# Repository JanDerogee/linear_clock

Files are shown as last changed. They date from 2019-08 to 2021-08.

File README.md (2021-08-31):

# linear_clock
A clock that shows time on a line instead of a circle.

Because sometimes, showing time in a different way can be easier.
Some people, mostly children have problems of reading time froma regular clock.
Times goes around in circles, but sometimes you just want to know where you are in a day.
This linear clock has one unique position for each moment of the day.
It is a true 24 hour clock. The night and morning are on the left of the scale, the afternoon and evening are on the right.
The clock reaches it highest point at the same time the sun does (well... theoretically, as this depends on your timezone).

The clock is simple in construction, requires just one single stepper motor and is based on an ESP8266 and a threaded rod.

For more information:
https://janderogee.com/projects/linear_clock/linear_clock.html

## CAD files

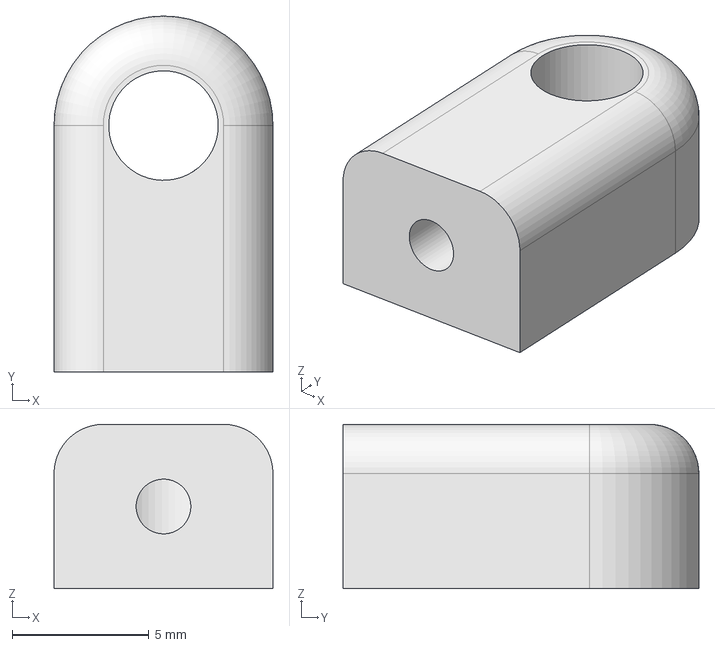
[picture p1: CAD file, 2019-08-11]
3d_printed_parts/lc_alarm_endcap.FCStd
8.00 x 13.0 x 6.00 mm

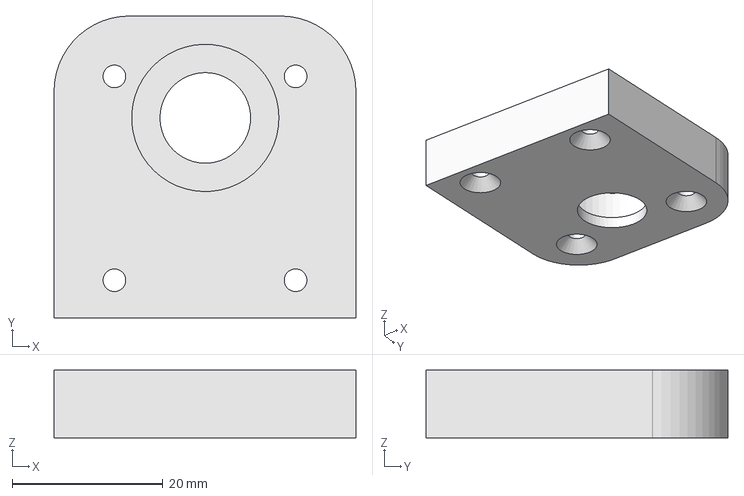
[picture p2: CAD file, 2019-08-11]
3d_printed_parts/lc_bearing_mount.FCStd
40.0 x 40.0 x 9.00 mm

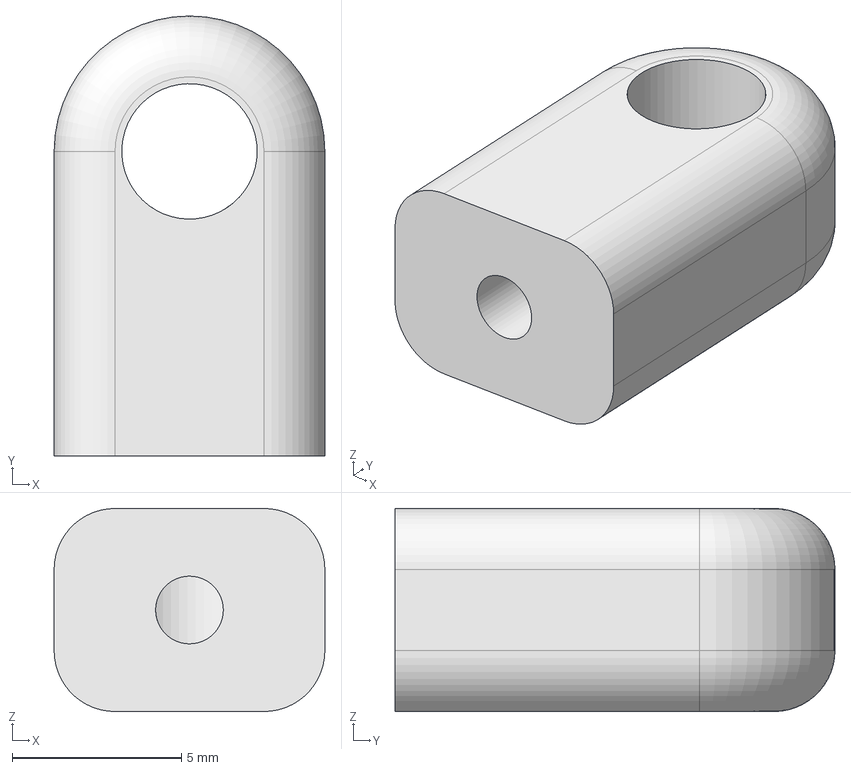
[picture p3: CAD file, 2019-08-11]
3d_printed_parts/lc_alarm_support.FCStd
8.00 x 13.0 x 6.00 mm

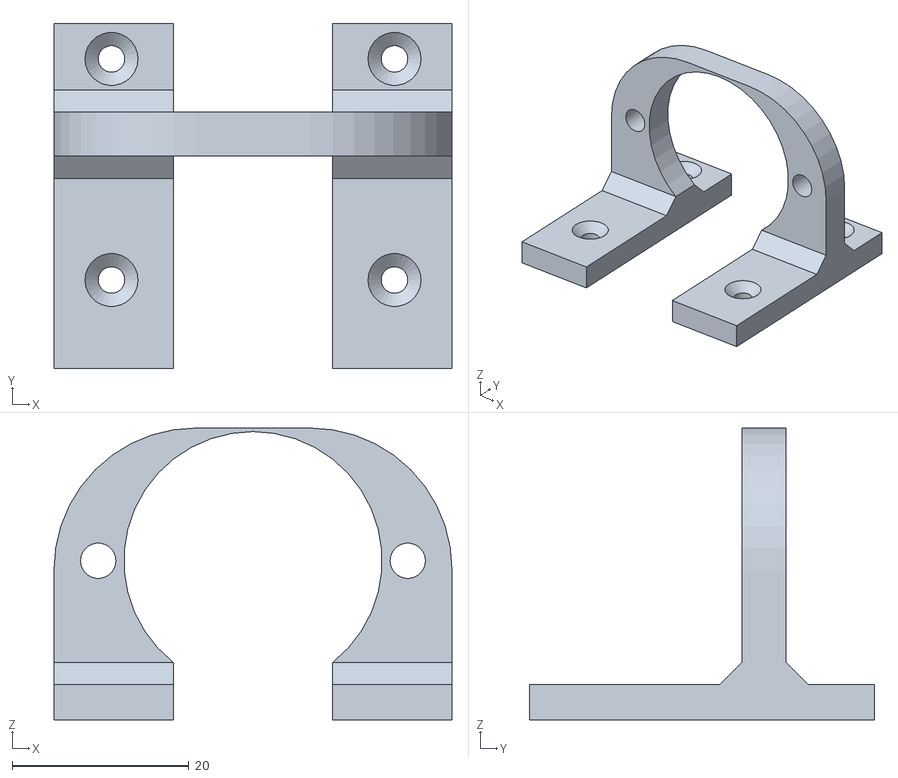
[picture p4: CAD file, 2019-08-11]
3d_printed_parts/lc_motor_mount.stl
45.0 x 39.0 x 33.0

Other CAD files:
3d_printed_parts/lc_moter_mount.FCStd
3d_printed_parts/lc_alarm_endcap.stl
3d_printed_parts/lc_alarm_support.stl
3d_printed_parts/lc_bearing_mount.stl

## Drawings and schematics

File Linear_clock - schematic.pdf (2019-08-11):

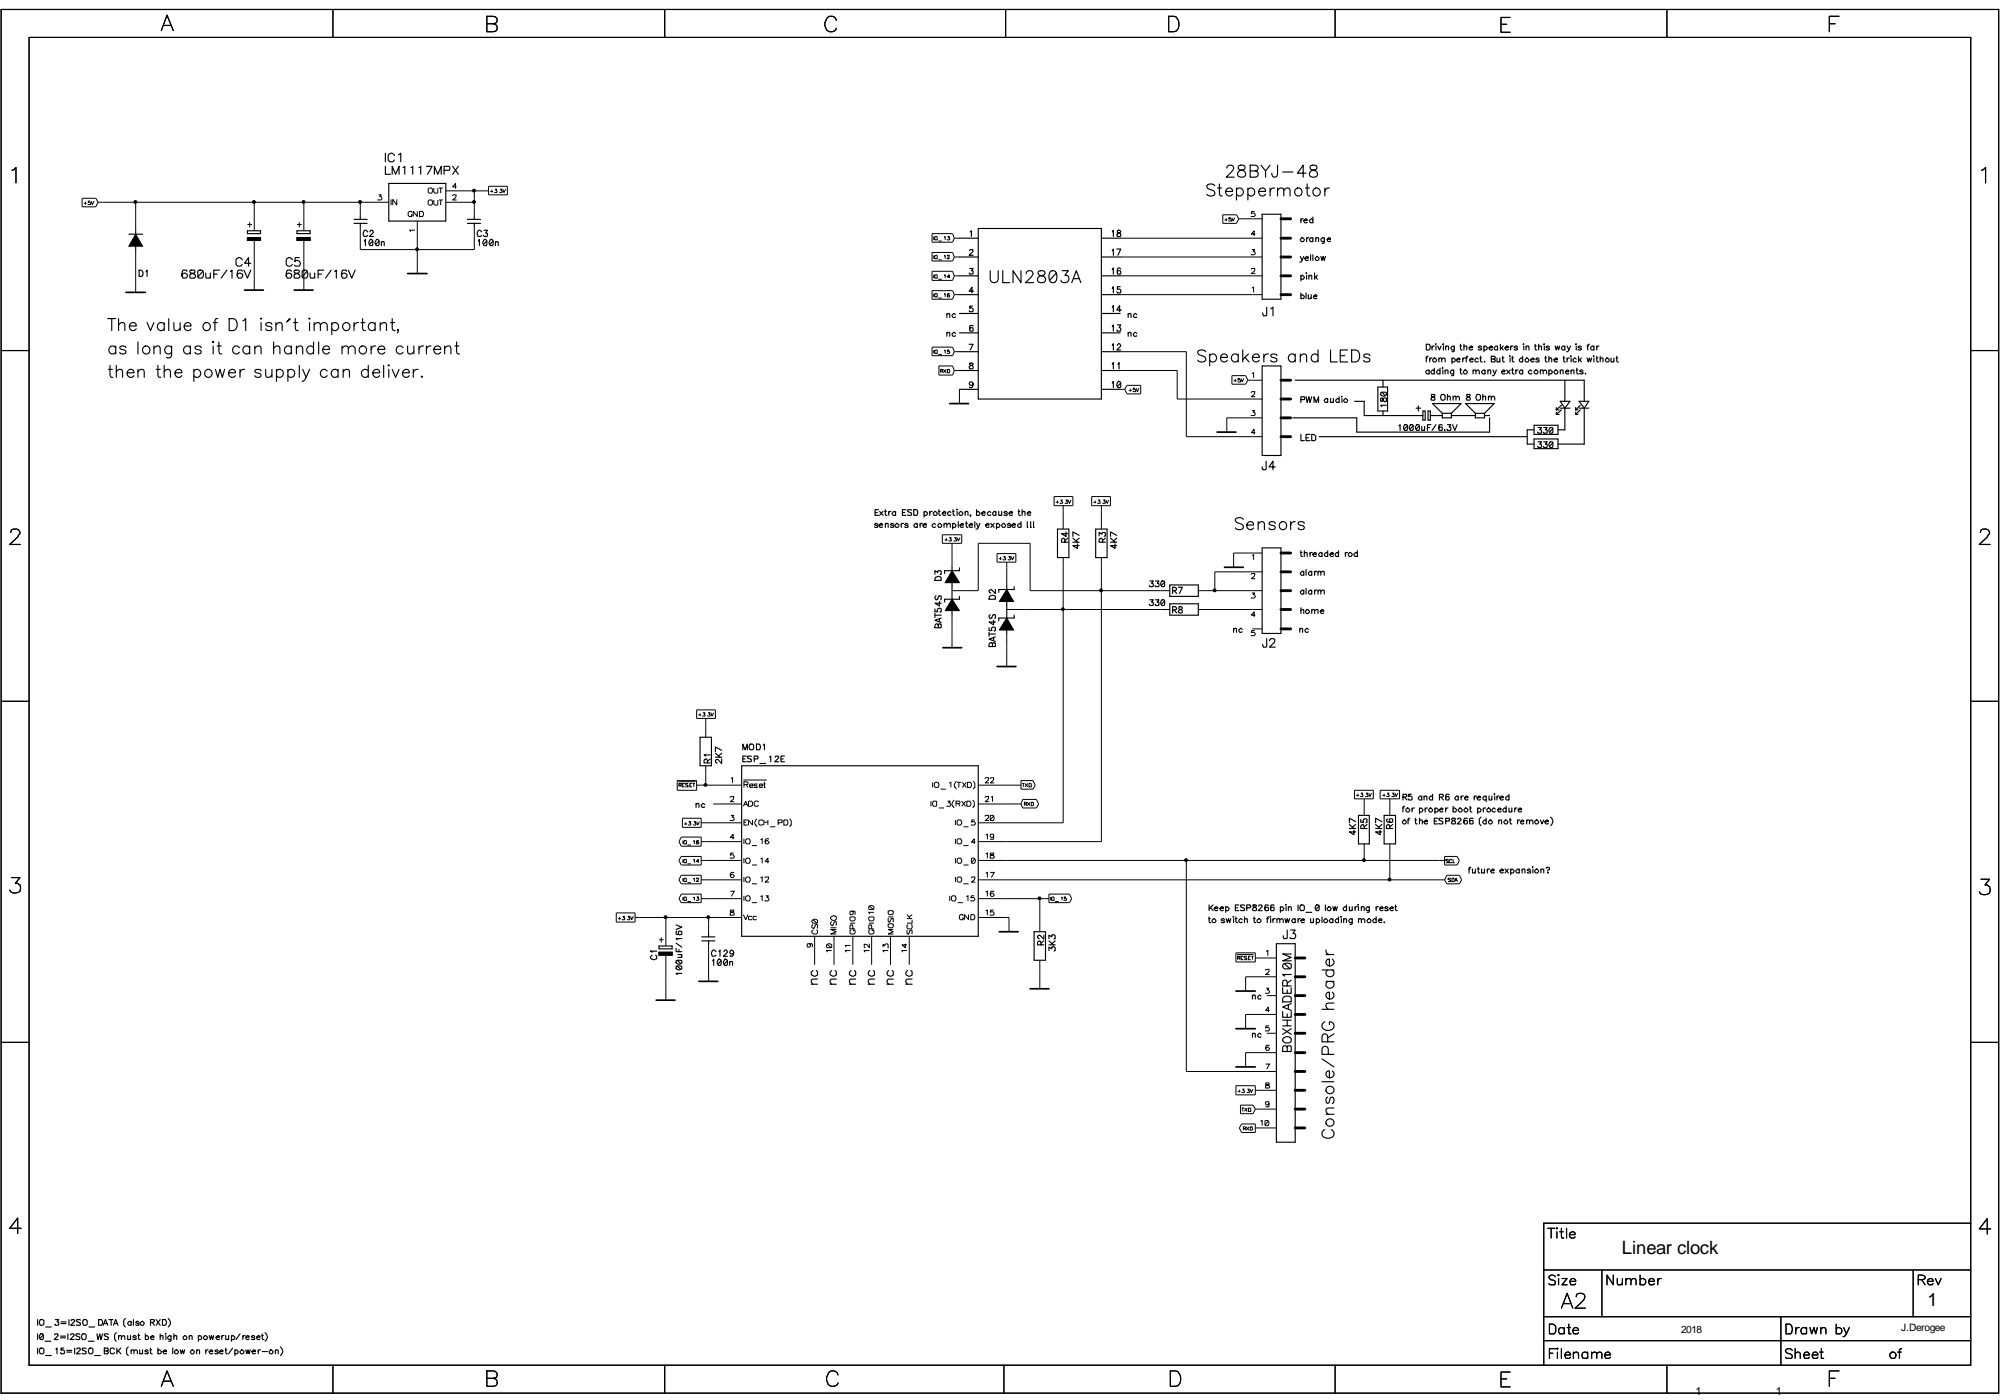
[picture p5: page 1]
Linear clock; J.Derogee

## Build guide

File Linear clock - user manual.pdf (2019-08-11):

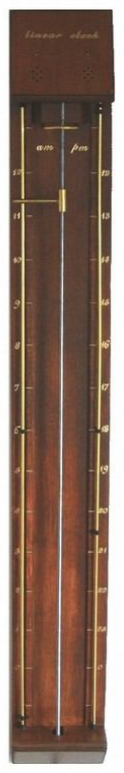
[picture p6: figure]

# Linear clock

## user manual

## Introduction

This manual describes the functionality and configuration of the linear clock. The linear clock is a project made by Jan Derogee. The entire project was created with the idea to make the mechanical part a simple as possible. This mainly with the intention that it could be easily reproduced by anyone. No special hardware or expensive parts required, only cheap and “off the shelf” parts that can be found in most hardware stores. This project also does not require the use of special limit switches, brushed contacts or an expensive spindle or nut.

I wanted to make this clock for many years but never took the time because I felt that it should be as easy to use as possible with the minimum of components, no display no buttons. It was mostly the revolution of the ESP8266 wifi module that made this project possible in an affordable (extremely cheap) and practical manor.

2018-05-07 | Page 2 of 13 | Linear clock – user manual

## Table of Contents

2018-05-07 | Page 3 of 13 | Linear clock – user manual

## 1 The linear clock

### 1.1 Concept

The idea behind the linear clock is mainly to be a different kind of time indicator. This because for some kind of people, indicating time by two rotating indicators isn't as easy as for others. For some it is far from convenient for others it is plainly confusing. In those cases a linear clock could be of use to small children who are not familiar with the concept of or capable of telling time using conventional clock. But for those who don't have trouble reading regular clocks, a linear clock can still be pretty to look at, decorating your wall and be a nice conversation starter when you have a visitor.

By representing time on a line (where the left side of the line represent night and morning and the right side represents afternoon and evening the complete overview of the current time/position of the day is indicated.

Indicating constantly repeating events at specific times along the day (think of breakfast, lunch, diner) is much easier when the whole day is represented. This could be of great use for learning rhythm and the concept of time to small children but could certainly be helpful in creating order and structure for autistic people who lack the skill of the concept of time and therefore cannot handle the method of representing the conventional way of displaying time.

### 1.2 Definition of the time scale

As can be seen on the photo on the next page, the timescale is defined in 2 sides. The left side (where the pointer moves upwards) indicates the time 00:00 – 11:59 and represents night and morning also known as AM. The right side of the clock indicates the time 12:00 – 23:59 and therefore represents afternoon and evening also known as PM.

Looking at the scale it becomes clear that the pointer moves in a similar way like the sun in our sky, it rises in the morning and sets in the afternoon.

2018-05-07 | Page 4 of 13 | Linear clock – user manual

## 2 The clock's parts

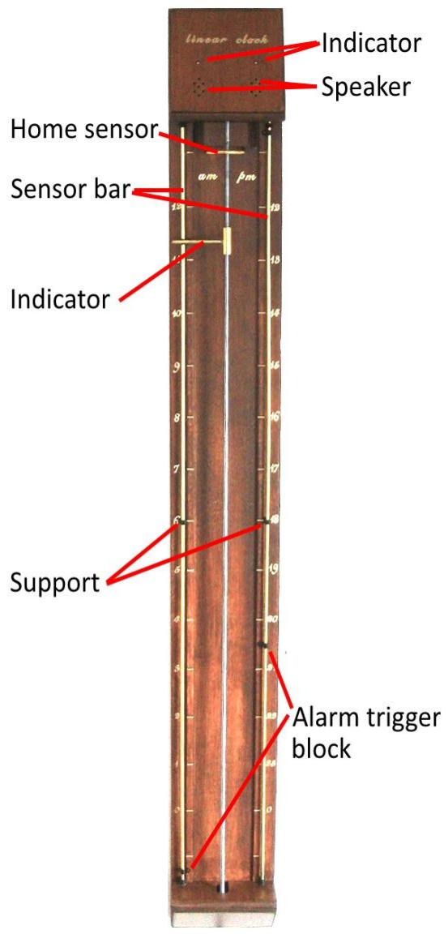
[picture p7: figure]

2018-05-07 | Page 5 of 13 | Linear clock – user manual

## 3 Configuration

This chapter will describe how to connect to the configuration page of the linear clock with an ordinary web browser and phone/tablet.

### 3.1 Connecting to your home network

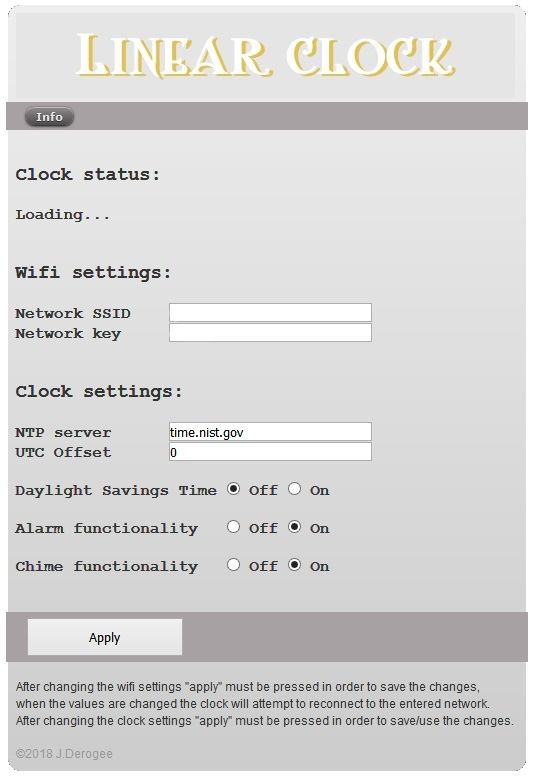
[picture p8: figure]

The linear clock has several settings that are required for correct operation. And although the clock has no display or button, it does feature a convenient web-interface through which these values can be altered.

However… when you first use the linear clock, it has no configuration for connecting to your home network and therefore it cannot connect to it. In order to allow you to access this configuration web-interface, the clock must create it's own network. Therefore allowing you to connect to it using your mobile phone or tablet.

This is what you need to do on your phone/tablet:

Step 1: go to the wifi configuration page of your phone/tablet
Step 2: scan through the list of available networks
Step 3: connect to the network Linear clock
Step 4: open a web browser on your phone/tablet
Step 5: enter the IP address 192.168.1.1 as an URL in your browser
Step 6: after a few seconds the configuration page will appear in your browser
Step 7: make sure you have the correct SSID and KEY values of your home network at hand
Step 8: change the settings of the SSID and KEY to the values of your home network
Step 9: when you've changed the values and pressed the apply button the created network Linear clock, will close and the clock will attempt to connect to your home network
Step 10: when SSID and KEY are correct, a cheerful sound will be heard and the LED will turn off. The clock will also be accessible through a browser on any computer/phone/tablet connected to your home network.

But when the settings are not correct, it will fail and you must return to step 3:

2018-05-07 | Page 6 of 13 | Linear clock – user manual

### 3.2 Settings

Below a screenshot of the configuration page of the linear clock. Although some settings are self explanatory, the next few chapters will describe each function in detail.

2018-05-07 | Page 7 of 13 | Linear clock – user manual

### 3.2.1 SSID

The SSID field should hold the name of your home network.

### 3.2.2 Key

The Key field should hold the network key (or password) of your home network.

### 3.2.3 NTP server

The linear clock requires an NTP server in order to function. Because this is where the clock get's the time from. The clock set's it's own internal clock to the NTP server time reference and is therefore very accurate. The NTP server is contacted every hour to keep the linear clock counter as accurate to the real time as possible.

A very good time server (and therefor set as the default value) is: time.nist.gov But if for some reason this fails to function there are many others and the clock allows you to change that setting.

### 3.2.4 UTC offset

The time that is received from the NTP server is according to the “coordinated universal time” or UTC for short. UTC is not affected in any way, so local jurisdictions regarding time zones or daylight saving time situations have no effect on the UTC value. This means that it is a world wide accepted universal time value that always requires an offset to be added in order to get the local time. For instance

Greenwich = UTC+0 | therefore fill in 0 in the UTC offset field if you use the clock there
Amsterdam = UTC+1 | therefore fill in 1 in the UTC offset field if you use the clock there
Chicago = UTC-6 | therefore fill in -6 in the UTC offset field if you use the clock there

For places that have timezones that are not a multiple of an whole hour an extra value can be added after the hour. But this fraction isn't in minutes but in parts of an hour. Therefore 15 minutes is 0.25 (because 15 minutes is 0.25 * 60). 30minutes is 0.5, 45 minutes is 0.75, etc.

Venezuela = UTC−4:30 | therefore fill in -4.5 in the UTC offset field if you use the clock there
Nepal = UTC+5:45 | therefore fill in 5.75 in the UTC offset field if you use the clock there

For more information about timezones you can visit https://en.wikipedia.org/wiki/Time_zone

Keep in mind that the offset from UTC is always without DST, in other words the offset is always related to wintertime. In order to add an extra hour because of summertime you should turn the DST setting to ON. Do not add the extra DST hour to your UTC offset setting but use the DST ON/OFF twice a year to switch between winter- (off) or summer-time (on).

Note:

If your life in an area that uses daylight savings time and it is summer time then if you life for example in a timezone that has an offset of +1 related to UTC, then do not fill in +2 to make the displayed time on the clock be correct. Just use offset +1 and set DST to ON. That would be the only correct way to configure your clock.

2018-05-07 | Page 8 of 13 | Linear clock – user manual

### 3.2.5 Daylight savings time

Daylight savings time or DST for short is a method of saving energy by messing with the clock. Therefore using the daylight more efficiently energy resources are less needed. Now this sounds nice in theory but in practice it is all very confusing because there are different DST changeover moments through the world, twice a year. Therefore in order to keep the design of the clock as easy as possible, DST is not automatic. Therefore the user must change the setting from OFF to ON and vice versa twice a year. When the summer begins DST should be set to ON and during winter DST should be set to OFF. The only thing that happens when DST is ON is that an extra hour is added to the local time.

### 3.2.6 Alarm

The clock features an alarm function, by placing alarm blocks along the brass sliders alarm event can be generated when the indicator passes over them. This functionality can be completely disabled, meaning that when it is in the OFF situation, the alarm blocks will be completely ignored.

### 3.2.7 Chime

The clock makes sounds, every quarter and on the hour. On the quarters the sound is just a tiny bell sound. On the hour it sounds a short melody followed by a loud bell for every hour. So when it's ten o clock, the loud bell sounds 10 times. The bell never sounds more then 12 times, so when it's 13:00 hours, the clock sounds just a single loud bell (not 13). Just like any other regular old chiming clock.

2018-05-07 | Page 9 of 13 | Linear clock – user manual

### 3.3 The IP address

The Linear clock, when properly configured, can connect to a wifi network. In order to reach the clock from your browser, you must know the IP address of the clock. Although this information is printed to the internal serial port for debugging, it is invisible to the regular user. Fortunately there are other ways to get this information.

One way would be to login the wifi-router that hosts the network. There you can see the list of currently connected devices (or recently connected devices). Below is a screenshot of the configuration menu of a router for an ordinary home network. In the list “Wifi settings” (on other routers this may be called “attached devices”) there are 2 devices listed, both the IP-addresses are shown. The linear clock is indicated by the hostname “linear-clock” and therefore can easily be found.

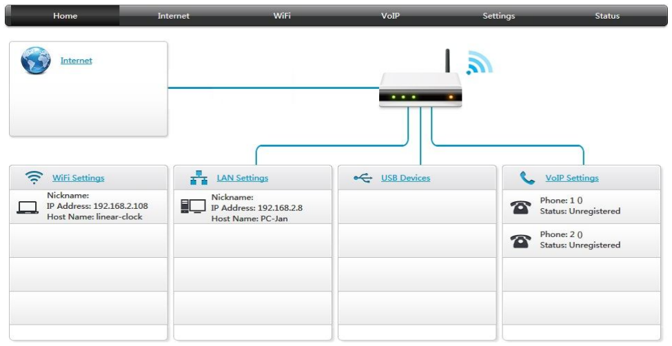
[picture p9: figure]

Another way could be by using a special app on your phone. One of those apps is “Fing” but this will not be described I this manual.

However… while using the IP-address always works, there is an easier way. But depending on your router and your browser this may not always work. You can connect to your clock by typing in your devices hostname followed by a / into the URL of your browser. So for the linear clock this would mean that the URL linear-clock/ must be entered in the browser. This is a lot more convenient then using the IP address method. Unfortunately this functionality cannot be guaranteed for all configurations and has proven difficult for some users.

2018-05-07 | Page 10 of 13 | Linear clock – user manual

## 4 Sounds

### 4.1 Alarms

The linear clock is capable of sounding an alarm at the desired time. An alarm event can be generated by preventing electrical contact between the indicator and the left or right sensor bar for more then 3 minutes. In order to create this situation the alarm trigger block(s) can placed at the desired location on the time scale / sensor bar.

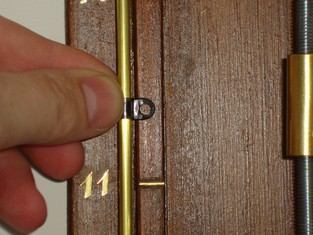
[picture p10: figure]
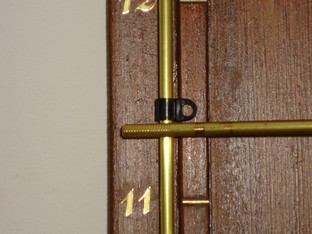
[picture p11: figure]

Even though the width of an alarm trigger block is 6mm wide this doesn't mean that the alarm will sound for the complete length of the block (6minutes). It sounds only when the indicator is at the center of the alarm trigger block. You may use as many trigger blocks as you like as long as they are at least 3mm apart. So that the indicator can always touch the sensorbar after an alarm event has been detected.
Due to the fact of the sensorbar being supported by an insulating part at the center of the sensorbar, alarm functionality close to the hours 6 and 18 is not possible.

When alarm functionality is not required the alarm trigger block(s) can be removed completely, but better is to slide them to the outer limits of the timescale. This way they don't get lost.

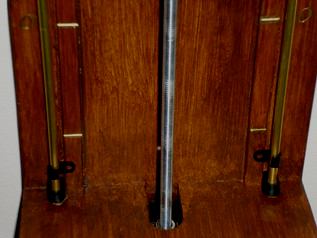
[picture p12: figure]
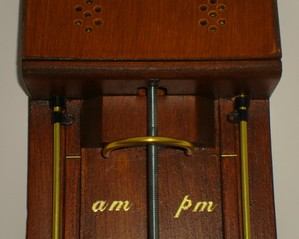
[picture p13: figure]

Alarms can also be completely disabled by changing the setting in the configuration menu. There when using the alarm functionality, make sure it is turned on in the settings.

2018-05-07 | Page 11 of 13 | Linear clock – user manual

### 4.2 Chimes

The design of the clock is like an old-skool or grandfather style clock. These clocks make sounds and therefore the linear clock also has these sounds.

The clock chimes at the whole hours indicating time with a short chime for each hour. Though to prevent it from making too much sound the clock chimes max 11 times.

2018-05-07 | Page 12 of 13 | Linear clock – user manual

## 5 Error codes

To indicate problems the clock has an indicator light that blinks in a special rhythm. This way there is no need for a display indicating the problem. Keeping the clock easy to build and pretty to look at. Because displays sometimes can completely ruin the look of a design.

The light blinks for … times and then pauses for 3 seconds and then repeats the pattern. Finding out the error code of the current problem, just count the blinks.

When the linear clocks starts, it will light the indicator lights continuously, when it is connected to the configured home network, the lights will go out and normal operation will resume.

### 5.1 Error code #1

Undefined error code.

This code does not exist, simply because it is a slightly confusing code. Blinking only once makes it confusing to count the blinks.

### 5.2 Error code #2

This code is reserved for future use.

### 5.3 Error code #3

Problem:
Mechanical error. The system could not detect the home reached signal.

Solution:
Check the electrical contacts (pointer) and the curved sensor bar at the top of the clock. The curved sensor bar is merely for making the clock look symetrical and has no further functions.

### 5.4 Error code #4

Problem:
NTP server error. The system could not connect to the NTP server.

It is very normal that this error occurs, this because the server fails to respond within the set timeout value. Though, sometimes this is just too short for the server to respond. Then again sometimes the server doesn't respond at all. The clock simply will try again within a few seconds and in many cases the problem will be solved just by waiting 15 seconds. However is this problem persists for more then 3 minutes, then there is could a serious problem that requires investigation.

Solution:
If this error persists for more then 3 minutes, check if the configured NTP server can be reached. If not then change the NTP server configuration in the settings menu for a server that does respond.
2018-05-07 | Page 13 of 13 | Linear clock – user manual

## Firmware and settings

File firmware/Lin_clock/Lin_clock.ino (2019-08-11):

/*
 *note to myself:
 *===============
 *to save precious resources (RAM) don't use Serial.println("hello world");
 *but use the macro Serial.println(F("hello world")); 
 *This way the text is not copied to a RAM variable, but it is read from flash
 *this saves a lot of RAM because in a large program there will be a lot of print
 *statements! In this relatively simple program this little "trick" saved us
 *1.5kBytes that's is a very much !!!
 */

#include <ESP8266WiFi.h>

//#include <WiFiClient.h> 
//#include <WiFiClientSecure.h>

#include <Wire.h>             /*lib. required for I2C functionality*/
#include <FS.h>               /*lib. required for audio playback (which uses spiffs)*/
#include "WebConfig.h"        /*the webserver to which the user can connect to configure the Cassiopei*/
#include "NTP.h"              /*Network Time Protocol (required to get time and date from a timeserver somewhere on the web*/

#include "AudioFileSourceSPIFFS.h"  /*this sketch requires the library "ESP8266Audio-master.zip" to be installed ( https://github.com/earlephilhower/ESP8266Audio )*/
#include "AudioGeneratorWAV.h"
#include "AudioOutputI2SNoDAC.h"  /*the cheap method of making sound*/
//#include <AudioOutputI2S.h>       /*the sophisticated way of making sound*/

/*Note to myself: if strange things happen when loading from SPIFFS, make sure that SPIFFS is still OK, by reloading it*/

/*------------------------------------------*/
/*           IO-pin definitions             */
/*------------------------------------------*/

//#define DEBUG_MODE  /*uncomment for debugging only (it disables all motor movements)*/

#define BAUDRATE          115200
#define TXD               1
#define RXD               3

#define SCL               0
#define SDA               2

#define SENSORBAR_UPDOWN  4   /*connected to the sensor bar for when the stepper is moving downwards*/
#define SENSORBAR_HOME    5   /*connected to the sensor bar for when the stepper is moving upwards*/

#define COIL_A            13  /*connected to orange wire of 28BYJ-48*/
#define COIL_B            14  /*connected to pink wire of 28BYJ-48*/
#define COIL_C            12  /*connected to yellow wire of 28BYJ-48*/
#define COIL_D            16  /*connected to blue wire of 28BYJ-48*/

#define LED               15  /*connected to speaker output*/

/*------------------------------------------*/
#define DOWN              0   /*direction definition for stepper motor*/
#define UP                1   /*direction definition for stepper motor*/

//#define STEPS_PER_REV     4096  /*the number of steps for a full rotation of the motor-shaft, we use M6, so a rev. is exactly 1 mm, the scale is 1mm/min, therefore 4096 steps=1min*/
#define STEPS_PER_REV     4076  /*the stepper isn't really 1:64 but 1:63.68395*/
/*for more 28BYJ-48 stepper info: https://grahamwideman.wikispaces.com/Motors-+28BYJ-48+Stepper+motor+notes */

#define HOME_POSITION     (11 * STEPS_PER_REV * 60) + (59 * STEPS_PER_REV) /*the number of steps away from 0:00*/
#define ALARM_THRESSHOLD  4     /*this is the halve of the width of the trigger block size in mm (or minutes)*/

/*----------------------------------------------------------------------------*/
/*the possible clock related functions*/
enum Clock_states      {CLOCK_IDLE,
                        CLOCK_HOME_TO_SENSOR_SETUP,
                        CLOCK_HOME_TO_SENSOR,
                        CLOCK_MOVE_TO_1159_SETUP,
                        CLOCK_MOVE_TO_1159,
                        CLOCK_OPERATE_SETUP,
                        CLOCK_OPERATE,
                        CLOCK_OPERATE_2,
                        CLOCK_OPERATE_3,
                        CLOCK_OPERATE_4,
                        CLOCK_ALARM_SETUP,
                        CLOCK_ALARM,
                        CLOCK_NTP_ERROR,
                        CLOCK_ERROR
                       }; 

/*----------------------------------------------------------------------------*/
unsigned long current_position = 0; /*use for stepper motor absolute position*/

/*----------------------------------------------------------------------------*/

void Clock_statemachine(void);
void MoveStepper(unsigned long steps, unsigned char dir, unsigned char spd);
void Motor_Off(void);
void Play_Chime_Melody(void);
void Play_Chime_Hour(void);
void Play_Chime_Quarter(void);
void Play_Chime_Magical(void);
void Play_Alarm(void);

/*----------------------------------------------------------------------------*/

AudioGeneratorWAV *wav;
AudioFileSourceSPIFFS *file;
AudioOutputI2SNoDAC *out;
//AudioOutputI2S *out;

/*============================================================================*/

void setup()
{ 
  //Wire.begin(SDA, SCL);       /*required for I2C functionality*/

  pinMode(SENSORBAR_UPDOWN, INPUT);
  pinMode(SENSORBAR_HOME, INPUT);
  pinMode(COIL_A, OUTPUT);      /*signal to stepper coildriver*/
  digitalWrite(COIL_A, LOW);    /*signal to stepper coildriver*/
  pinMode(COIL_B, OUTPUT);      /*signal to stepper coildriver*/
  digitalWrite(COIL_B, LOW);    /*signal to stepper coildriver*/
  pinMode(COIL_C, OUTPUT);      /*signal to stepper coildriver*/
  digitalWrite(COIL_C, LOW);    /*signal to stepper coildriver*/
  pinMode(COIL_D, OUTPUT);      /*signal to stepper coildriver*/
  digitalWrite(COIL_D, LOW);    /*signal to stepper coildriver*/
  pinMode(LED, OUTPUT);         /*indicator LED*/
  digitalWrite(LED, LOW);       /*indicator lights off*/ 

  Serial.begin(BAUDRATE);
  Serial.println();
  Serial.println(F("\r\n--== Linear clock ==--"));
  Serial.println(F("Firmware version:" __DATE__ ));
  
  #ifdef DEBUG_MODE        /*alaert the programmer we arein debugging mode*/
  Serial.println(F("ATTENTION: debugging mode, all movement disabled"));
  #endif
  
  //Serial.print(F("PGM flash size ="));
  //Serial.println(ESP.getFlashChipSize()); /*this will only give the correct results if the proper settings have been made. To do so simply select the proper board in the Arduino IDE: Tools -> board*/
  //Serial.print(F("Free heap size =")); /*show available RAM*/
  //Serial.println(ESP.getFreeHeap()); /*show available RAM*/

  Serial.println(F("Mounting FS...")); /*required for webserver, settings and sample playback*/
  if (SPIFFS.begin() == false)
  {
    Serial.println(F("Failed to mount file system"));
    ESP.restart();  /*force reset on failure*/
  } 
  
  digitalWrite(LED, HIGH);      /*indicator lights on, they will turn off when connected to a network*/   
  WebConfig_init();             /*get the configuration from the config.json file as stored in the SPIFFS filesystem, when connected to the network start the webserver*/
  Webserver_process();    
  digitalWrite(LED, LOW);       /*indicator lights off, we are connected to a network*/ 

  /*ATTENTION:, don't play samples before calling WebConfig_init() as it WILL crash the ESP (has something to do with declaring of the "out" object (don't ask me why, but it works better this way)*/
  out = new AudioOutputI2SNoDAC();  /*this initialisation is required for all audio playback code, initialze the object here because it is not good (and not needed) to do this in the playback routine*/  
  Play_Chime_Magical();             /*indicate that we've powered up and that we are connected to the specified network*/  
}


void loop()
{  
  while(1)
  {
    yield();                      /*pet the watchdog*/
    Webserver_process();          /*handle webserver and therefore stay as responsive as is practically possible*/    
    yield();                      /*pet the darn beast again... just to make sure it stays drowsy*/
    Clock_statemachine();         /*do what needs to be done to make this clock a clock*/
  }   
}

/*==================================================================*/

/*======================================================================================================================*/
/*                                        Statemachine for all Clock related functions                                  */
/*======================================================================================================================*/
void Clock_statemachine(void)
{
  static unsigned char Clock_state = CLOCK_IDLE;
  static long timeout = 0;  
  static unsigned char error_code = 0;
  static unsigned char lp = 0;
  static unsigned long new_position = 0;
  static unsigned long steps = 0;
  static unsigned char dir = UP;
  static unsigned char prev_hour = 0;
  static unsigned char prev_minute = 0;
  static unsigned char alarm_cnt = 0;
  static long value = 0;
  
  switch(Clock_state)
  {
    case CLOCK_HOME_TO_SENSOR_SETUP:
    {
      Serial.println(F("Starting homing procedure"));  /*home the runner to hit the limit-switch*/
      cfg.status_msg = "Homing indicator...";       /*update the status message*/
      timeout = 15 * STEPS_PER_REV * 60;            /*scale is 14 hours, so if we haven't found anything after a distance of 15hours, then there is a serious problem and we should abort*/
      Clock_state = CLOCK_HOME_TO_SENSOR;
      break;
    }
    
    case CLOCK_HOME_TO_SENSOR:
    {
      if(timeout > 256)
      {
        timeout = timeout - 256;
      }
      else
      {
        Serial.println(F("timeout exceeded, service required"));      
        Serial.println(F("limit sensor could not be detected"));
        Play_Alarm();     /*could not home the runner*/
        error_code = 3;
        Clock_state = CLOCK_ERROR;
        break;
      }

#ifndef DEBUG_MODE        /*for debugging purposes, it can be usefull to disable movement*/    
      MoveStepper(256, UP, 1);  /*move stepper 0.0625mm up before checking the sensor again*/    

      if(digitalRead(SENSORBAR_HOME) == false)        /*home the runner to hit the limit-switch (sensor signal goes low when home reached)*/
      {
        cfg.status_msg = "Home sensor detected";       /*update the status message*/        
        Clock_state = CLOCK_MOVE_TO_1159_SETUP;        
      }      
#else
      Clock_state = CLOCK_MOVE_TO_1159_SETUP;        
#endif      

      break;
    }

    case CLOCK_MOVE_TO_1159_SETUP:
    {
      Play_Chime_Quarter();
      Serial.println(F("home reached, moving to 11:59"));
      cfg.status_msg = "Moving to 11:59";       /*update the status message*/        
      new_position = 58*STEPS_PER_REV;  /*move the stepper to the point 11:59 on the scale*/
      Clock_state = CLOCK_MOVE_TO_1159;
      break;
    }
                       
    case CLOCK_MOVE_TO_1159:
    {          
      cfg.status_msg = "Moving indicator, ";            /*update the status message*/              
      cfg.status_msg += new_position;                   /*traveling the entire distance in one command would take too long*/
      cfg.status_msg += " steps";                       /*therefore we split up the move action in smaller steps. This requires*/
                               
      if(new_position > 256)                            /*much more code but it will have the benefit of a fully responsive web interface*/
      {
        new_position = new_position - 256;              /*decrement by the number of done steps*/
        MoveStepper(256, DOWN, 1); 
      }
      else
      {
        MoveStepper(new_position, DOWN, 1);             /*the last piece of the new_position movement*/
        current_position = HOME_POSITION;               /*the system is homed, therefore (re)set the position counter*/          
        Clock_state = CLOCK_OPERATE_SETUP;          
      }
      break;
    }

    case CLOCK_OPERATE_SETUP:
    {
      NTP_init(cfg.ntp);  /*initialize NTP functionality (in order to get time and date from a timeserver)*/
      Clock_state = CLOCK_OPERATE;
      break;
    }

    case CLOCK_OPERATE:
    {
      value = 60*60 * cfg.offset;   /*because the offset (timezone) and dst setting can be changed by the user at any time, it is best that we calculate and parse this value every time*/
      if (cfg.dst == true)          /*normally this would not be important, but in this case we want the user settings to take effect immediately*/
      {
        value = value + (60*60);    /*when DST is enabled, add another hour to the offset value*/
      }
      NTP_offset(value);            /*parse the value to the NTP routines*/
      
      NTP_statemachine();           /*get and/or update the time*/  

      cfg.status_msg = "Local time = ";      /*update the status message*/
      cfg.status_msg+= NTP_struct.year;    
      cfg.status_msg+= "-";
      cfg.status_msg+= NTP_struct.month;
      cfg.status_msg+= "-";
      cfg.status_msg+= NTP_struct.day;
      cfg.status_msg+= " ";
      cfg.status_msg+= NTP_struct.hour;
      cfg.status_msg+= ":";
      if(NTP_struct.minute < 10)  {cfg.status_msg+= "0";} /*check if we must add an additionl 0 to maintain the 2 digit representation*/
      cfg.status_msg+= NTP_struct.minute;
      cfg.status_msg+= ":";    
      if(NTP_struct.second < 10)  {cfg.status_msg+= "0";} /*check if we must add an additionl 0 to maintain the 2 digit representation*/
      cfg.status_msg+= NTP_struct.second;      
      
      if(NTP_struct.synced == true)     
      {
        cfg.status_msg+= " (synced)";
        if((NTP_struct.hour != prev_hour) || (NTP_struct.minute != prev_minute))  /*only update the clock when the time has changed*/
        {
          Clock_state = CLOCK_OPERATE_2;
        }
      }
      else                              
      {
        cfg.status_msg+= " (NTP err.)";
        Clock_state = CLOCK_NTP_ERROR;       
      }

#ifdef DEBUG_MODE        /*for debugging purposes, it can be usefull to disable movement*/    
      Serial.print(F("Status msg: "));
      Serial.println(cfg.status_msg);
      delay(1000);  /*slow down the stream of printf messages...*/
#endif      


      /*we must check the sensorbar signal as much as we can, this way we reduce the odds of a false trigger due to dirty/noisy contacts*/
      if(digitalRead(SENSORBAR_UPDOWN) == false)  
      {
        alarm_cnt = 0;  /*reset counter (event may be over or the previous trigger was false)*/
      }  
      break;
    }

    case CLOCK_OPERATE_2:
    {                            
      prev_hour = NTP_struct.hour;
      prev_minute = NTP_struct.minute;
  
      /*calculate how many steps since 0:00 we must do to reach the new time*/   
      if(NTP_struct.hour < 12)  
      {
        new_position = (NTP_struct.hour * STEPS_PER_REV * 60) + (NTP_struct.minute * STEPS_PER_REV);                        /*this is the number of steps from 0:00 (on the right side of the scale)*/
      }
      else                      
      {
        new_position = HOME_POSITION - ((STEPS_PER_REV * (NTP_struct.hour-12) * 60) + (STEPS_PER_REV * NTP_struct.minute)); /*this is the number of steps from 0:00 (on the right side of the scale)*/
      }
      
      Serial.print(F("current:"));
      Serial.print(current_position);
      Serial.print(F(", requested:"));
      Serial.println(new_position); /*move the steppermotor to the calculated position*/      

      if(new_position < current_position)
      {
        steps = current_position - new_position;
        dir = DOWN;
        Serial.print(F("down "));
        Serial.print(steps);
        Serial.println(F(" steps")); 
      }
      else
      {
        steps = new_position - current_position;
        dir = UP;        
        Serial.print(F("up "));
        Serial.print(steps);
        Serial.println(F(" steps"));    
      }
      
      Clock_state = CLOCK_OPERATE_3;
      break; 
    }

    case CLOCK_OPERATE_3:
    { 
      cfg.status_msg = "Moving indicator, ";              /*update the status message*/              
      cfg.status_msg += steps; 
      cfg.status_msg += " steps";
      Serial.println(cfg.status_msg);
      if(steps > 256)                                   /*much more code but it will have the benefit of a fully responsive web interface*/
      {
        steps = steps - 256;                            /*decrement by the number of done steps*/
        MoveStepper(256, dir, 1);
      }
      else
      {
        MoveStepper(steps, dir, 1);                     /*the last piece of the new_position movement*/
        Motor_Off();                                    /*shut down the motors to save energy*/                                            
        Clock_state = CLOCK_OPERATE_4;          
      }     
      break;
    }

    case CLOCK_OPERATE_4:
    { 
      /*chime on the whole hour and sound the number of hours*/
      if(cfg.chime == true)
      {
        if(NTP_struct.minute == 0)
        {
          cfg.status_msg = "Playing hourly chime";              /*update the status message*/                       
          Play_Chime_Melody();
          lp=20;
          while(lp>0)   /*small delay othwerwise the first hour chime will be not noticed*/
          { 
            yield();                      /*pet the watchdog*/
            Webserver_process();          /*handle webserver and therefore stay as responsive as is practically possible*/    
            delay(100);
            lp--;            
          }
          
          
          lp = NTP_struct.hour;
          if(lp > 12)    /*reduce the number of chimes to 12... technically 11*/
          {
            lp = lp - 12;
          }
          
          while(lp>0)
          { 
            yield();                      /*pet the watchdog*/
            Webserver_process();          /*handle webserver and therefore stay as responsive as is practically possible*/    
            Play_Chime_Hour();
            lp--;            
          }
        }
      
        /*chime every 15 minutes*/
        if((NTP_struct.minute == 15) || (NTP_struct.minute == 30) || (NTP_struct.minute == 45))
        {
          Play_Chime_Quarter();
        }
      }

      if(cfg.alarm == true)
      {
        if(digitalRead(SENSORBAR_UPDOWN) == true)
        {
          alarm_cnt++;    /*increment alarm counter, if high enough the thresshold will be passed and the alarm will sound*/
        }
        else
        {
          alarm_cnt = 0;  /*reset counter (event may be over or the previous trigger was false)*/
        }
        
        if(alarm_cnt == ALARM_THRESSHOLD)
        {            
          if(((NTP_struct.minute >= 57) || (NTP_struct.minute <= 3)) && ((NTP_struct.hour == 6) || (NTP_struct.hour == 18)))
          {
            Clock_state = CLOCK_ALARM_SETUP;  
          }
        }
      }
      Clock_state = CLOCK_OPERATE;
      break;
    }
    
    case CLOCK_ALARM_SETUP:
    {
      cfg.status_msg = "Alarm event";   /*update the status message*/      
      lp = 5; /*the number of times the alarm sound should be played*/
      Clock_state = CLOCK_ALARM;      
      break;
    }   

    case CLOCK_ALARM:
    {      
      Play_Alarm();
      delay(500);
      if(lp-- == 0)
      {  
        Clock_state = CLOCK_OPERATE;
      }
      break;
    }   

    case CLOCK_NTP_ERROR:
    {
      Serial.println(F("NTP time unavailable"));
      cfg.status_msg = "Error: #4";   /*update the status message*/
      for(lp=4; lp>0; lp--)
      {
        digitalWrite(LED, HIGH);  /*light the indicator LED, there is a problem*/                
        delay(500);
        digitalWrite(LED, LOW);  /*light the indicator LED, there is a problem*/                
        delay(500);
      }
      digitalWrite(LED, LOW);
      delay(3000);    
      Clock_state = CLOCK_OPERATE;      
      break;
    }   
       
    case CLOCK_ERROR:
    {
      /*blink the LED to indicate an error situation*/
      cfg.status_msg = "Error: #";      /*update the status message*/
      cfg.status_msg += error_code;     /*update the status message*/
      for(lp=error_code; lp>0; lp--)
      {
        digitalWrite(LED, HIGH);  /*light the indicator LED, there is a problem*/                
        delay(500);
        digitalWrite(LED, LOW);  /*light the indicator LED, there is a problem*/                
        delay(500);
      }
      digitalWrite(LED, LOW);
      delay(3000);    
      break;
    }   
 
    case CLOCK_IDLE:
    default:
    {
      Clock_state = CLOCK_HOME_TO_SENSOR_SETUP;
      break;
    }
  }
}

/*======================================================================================================================*/
/*                                                     other subroutines                                                */
/*======================================================================================================================*/
/*play the hourly melody before the actual chiming starts*/
void Play_Chime_Melody(void)
{ 
  yield();
  file = new AudioFileSourceSPIFFS("/clock_melody.wav"); 
  wav = new AudioGeneratorWAV();
  wav->begin(file, out);
  while(wav->isRunning())
  {
    yield();
    if (!wav->loop()) wav->stop();
  }
  delete file;  /*when done so time to clean up*/
  delete wav;  
  /*led output is also a pin that is used by the I2S port, therefore we must restore it back to IO when done playing the sample*/
  pinMode(LED, OUTPUT);         /*indicator LED*/
  digitalWrite(LED, LOW);       /*should be off*/
}

/*play the chime (indicating the hours) as many times as required, the last chime will be the sample with the extra long duration*/
void Play_Chime_Hour(void)
{
  yield();
  file = new AudioFileSourceSPIFFS("/clock_chime_short.wav");     
  wav = new AudioGeneratorWAV();
  wav->begin(file, out);
  while(wav->isRunning())
  {
    yield();    
    if (!wav->loop()) wav->stop();
  } 
  delete file;  /*when done so time to clean up*/
  delete wav;  
  /*led output is also a pin that is used by the I2S port, therefore we must restore it back to IO when done playing the sample*/
  pinMode(LED, OUTPUT);         /*indicator LED*/
  digitalWrite(LED, LOW);       /*should be off*/ 
}
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

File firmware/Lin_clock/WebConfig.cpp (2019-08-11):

#include <Arduino.h>      /*important to avoid all sorts of strange error messages*/
#include <ArduinoJson.h>  /*this can be installed using the arduino library manager, it is in the list, but not installed by default*/
#include <FS.h>
#include "WebConfig.h"
#include <ESP8266WiFi.h>
#include <ESP8266WebServer.h>

/*-------------------------------------------------------------------------*/

ESP8266WebServer server(80);

/*--------------------------------------------------------------*/
config_structTYPE cfg;  /*structure holding all the settings and variables that should be available to all callers who includes this .h file*/
/*--------------------------------------------------------------*/

/*----------------------------------------------------------------*/
bool Config_load(void);                   /*load settings from JSON configuration file*/
bool Config_save(void);                   /*save settings to JSON configuration file*/
void Webserver_init(void);                /*init webserver routines*/

void settings_send(unsigned char var);

void returnOK(void);
void returnFail(String msg);
String getContentType(String filename);
bool handleFileRead(String path);
void handleNotFound(void);
void redirect_to_mainmenu(void);

/*================================================================/*

/*do SPIFFS.begin() before calling WebConfig_init();*/
/*this routine will open the SPIFFS, read the JSON configuration file and connect to the specified network*/
/*if that network can't be found then an acces point is created, so that the user can connect using his/her phone/tablet*/
/*and fill in the correct settings, if these settings are correct, then this function will exit and normal code can*/
/*continue, therefore no wifimanager or hardcoded settings are required. Everything is conveniently stored in the JSON file*/
/*these files are to be located along with the webserver files in the /data folder of the sketch folder*/
void WebConfig_init(void)
{
  unsigned int nmbr_of_networks=0;
  unsigned int i=0;
  bool network_ok = false;
  unsigned char timeout = 0;
  char c_ssid[32];  /*working register to port the value of the SSID to the wifi network routines (which require char and not String)*/
  char c_key[32];  /*working register to port the value of the key to the wifi network routines (which require char and not String)*/
  String prev_ssid = "";  /*variable to keep track of a changing SSID*/
  String prev_key = "";   /*variable to keep track of a changing KEY*/

  if(Config_load() == false)
  {
    ESP.restart();  /*force reset on failure*/
  } 

  while(1)  /*keep looping here until we are connected to a real network*/
  {
    prev_ssid = cfg.ssid;
    prev_key = cfg.key;
    
    Serial.println(F("scanning for networks"));   
    WiFi.disconnect();                /*only required when the Cassiopei is reset, this is not required when the cassiopei is power-on*/
    WiFi.persistent(false);           /*Do not memorise new wifi connections*/
    //ESP.flashEraseSector(0x3fe); // Erase remembered connection info. (Only do this once).
    WiFi.mode(WIFI_STA);              /*connect to an existing WiFi network (the ESP8266 will be used as a STATION)*/
    WiFi.hostname(WIFIHOSTNAME);      /*the name of this device. This name is shown in the list of connected devices in your router*/
    nmbr_of_networks = WiFi.scanNetworks(); /*WiFi.scanNetworks will return the number of networks found*/
    if (nmbr_of_networks > 0)
    {
      for (i=0; i<nmbr_of_networks; ++i)  /*show all the found networks*/
      {
        Serial.print(WiFi.SSID(i));
        Serial.print(F(" ("));
        Serial.print(WiFi.RSSI(i));
        Serial.print(F(" dB)"));
        Serial.println((WiFi.encryptionType(i) == ENC_TYPE_NONE)?" ":"*");
        delay(1); /*we could also yield*/
      }

      Serial.print(F("Searching for:"));       /*attempt to connect to preferred network*/
      Serial.print(cfg.ssid);
      network_ok = false;   /*unless we find something, we fail*/               
      for (i=0;i<nmbr_of_networks;++i)
      {
        delay(1); /*we could also yield*/
        if(cfg.ssid == WiFi.SSID(i))        /*compare network name with name from list, try them all until we find a match*/
        {
          Serial.println(F(",found"));                               /*network has been found, now try to connect*/
          cfg.ssid.toCharArray(c_ssid, (cfg.ssid.length()+1));    /*this crazy construction is required because wifi.begin cannot accept strings ?!?!?!*/
          cfg.key.toCharArray(c_key,(cfg.key.length()+1));        /*this crazy construction is required because wifi.begin cannot accept strings ?!?!?!*/       
          Serial.println(F("Connecting..."));
          WiFi.begin(c_ssid, c_key);
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
